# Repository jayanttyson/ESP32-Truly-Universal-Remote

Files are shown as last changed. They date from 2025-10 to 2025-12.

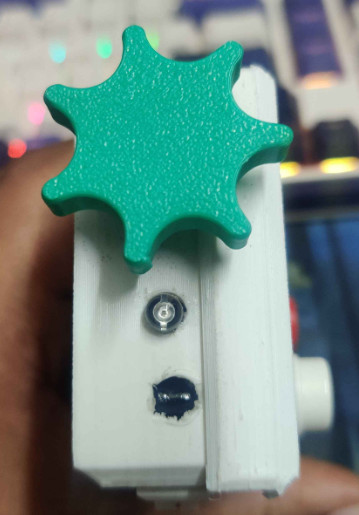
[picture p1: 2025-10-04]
Images/10.png

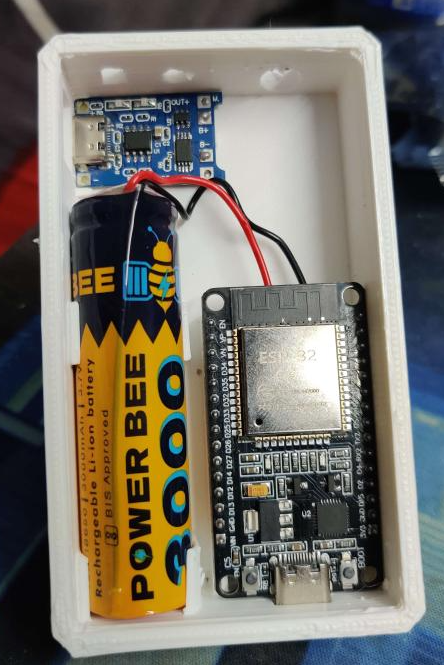
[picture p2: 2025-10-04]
Images/1.png

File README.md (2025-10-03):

# ESP32-Truly-Universal-Remote
ESP32-based universal remote control with IR, Bluetooth, and OLED display capabilities.
# Domninus Scepter: ESP32 IR/Bluetooth Remote Control


**Domninus Scepter** is a versatile ESP32-based IR/Bluetooth remote control system designed to control infrared devices such as TVs, air conditioners (ACs), and speakers, with additional Bluetooth keyboard functionality for media control. It features an OLED display for user interaction, a rotary encoder for navigation, and persistent storage for IR codes. The project supports a wide range of IR protocols and includes deep sleep for power efficiency.

## Features
- **IR Control**: Supports multiple IR protocols (NEC, Sony, Samsung, Coolix, Daikin, Mitsubishi, etc.) for TVs, ACs, and speakers.
- **Bluetooth Keyboard**: Controls media playback (play/pause, volume, mute) on Android/Windows devices via BLE.
- **OLED Display**: Shows menu, selected profile, battery status, and feedback messages.
- **Rotary Encoder**: Navigate profiles and modes with a rotary encoder and button.
- **Persistent Storage**: Saves IR codes and settings using the ESP32's NVS (Preferences).
- **Battery Monitoring**: Displays battery percentage based on voltage readings.
- **Deep Sleep**: Enters low-power mode after 15 seconds of inactivity to conserve battery.
- **Debug Mode**: Extensive serial output for debugging (enable with `#define DEBUG`).

## Hardware Requirements
- **ESP32 Board** (e.g., ESP32 DevKitC)
- **IR Receiver** (e.g., TSOP4838, connected to GPIO 15)
- **IR LED** (connected to GPIO 4)
- **OLED Display** (128x64, SSD1306, I2C, address 0x3C)
- **Rotary Encoder** (CLK: GPIO 25, DT: GPIO 26, SW: GPIO 27)
- **Push Buttons**:
  - BTN1 (Play/Pause): GPIO 33
  - BTN2 (Volume Up): GPIO 32
  - BTN3 (Mute): GPIO 13
  - BTN4 (Volume Down): GPIO 12
  - REC (Device Switch/Record): GPIO 5
- **Battery Monitoring**: Voltage divider connected to GPIO 34, used 2 x 1MΩ for Minimum Battery Drainage
- **Debug LED**: GPIO 2 {inbuild LED}/(optional, for visual feedback)
- 2N2222 General Purpose Transistor for IR LED
- 5v voltage regulator for powering the ESP32 with a stable Voltage
- 0.1uf Ceramic Capacitor at GPIO34 to GND for signal filtering (highly recomended)

## Software Requirements
- **Arduino IDE** (2.x recommended)
- **ESP32 Board Support**: Install via Boards Manager (`esp32` by Espressif)
- **Libraries**:
  - [IRremoteESP8266](https://github.com/crankyoldgit/IRremoteESP8266) (v2.8.2 or higher)
  - [Adafruit_SSD1306](https://github.com/adafruit/Adafruit_SSD1306) (for OLED)
  - [Preferences](https://github.com/espressif/arduino-esp32) (included with ESP32 core)
  - [NimBLE-Arduino](https://github.com/h2zero/NimBLE-Arduino) (for BLE)
  - [BleKeyboard](https://github.com/T-vK/ESP32-BLE-Keyboard) (for Bluetooth keyboard)

## Installation
1. **Clone the Repository**:
   ```bash
   git clone https://github.com/jayanttyson/ESP32-Truly-Universal-Remote.git
Install Arduino IDE:Download and install from arduino.cc.

Install ESP32 Board Support:In Arduino IDE, go to File > Preferences, add the following to Additional Boards Manager URLs:

https://raw.githubusercontent.com/espressif/arduino-esp32/master/package_esp32_index.json

Go to Tools > Board > Boards Manager, search for esp32, and install.

Install Libraries:In Arduino IDE, go to Sketch > Include Library > Manage Libraries.
Install IRremoteESP8266 (v2.8.2+), Adafruit_SSD1306, NimBLE-Arduino, and BleKeyboard.

Open the Sketch:Open domninus_scepter.ino from the cloned repository in Arduino IDE.

Configure and Upload:Select your ESP32 board under Tools > Board (e.g., ESP32 Dev Module).
Connect the ESP32 via USB, select the correct port under Tools > Port.
Upload the sketch (Sketch > Upload).

UsagePower On:Connect the ESP32 to a power source (e.g., battery or USB).
The OLED displays the menu with available profiles: TV, AC, SPK, AC_X, BT.

Navigate Profiles:Rotate the encoder to highlight a profile.
Press the encoder button to select the profile or toggle between menu and control mode.

Record IR Commands:In control mode, press the REC button (GPIO 5) to enter record mode (REC appears on OLED).
Point the target remote at the IR receiver and press a button.
If successful, the OLED shows "Signal captured! Press BTN1/2/3/4 to save".
Press a button (1-4) to save the IR code to that button for the current profile.

Send IR Commands:In control mode, press BTN1, BTN2, BTN3, or BTN4 to send the saved IR command.
For AC profiles (AC, AC_X), supports protocols like Coolix, Daikin, etc.
For TV/SPK, supports NEC, Sony, etc., or raw IR codes.

Bluetooth Mode:Select the BT profile.
Pair with a device (Android/Windows) via Bluetooth settings (device name: Domninus Scepter).
Use BTN1 (Play/Pause), BTN2 (Volume Up), BTN3 (Mute), BTN4 (Volume Down).
Press REC to switch between Android and Windows profiles.

Battery Monitoring:Battery percentage is displayed on the OLED, updated every 30 seconds.

Deep Sleep:The device enters deep sleep after 15 seconds of inactivity to save power.
Wake by pressing the encoder button (GPIO 27).

DebuggingEnable Debug Mode:Uncomment #define DEBUG in the sketch to enable serial output at 115200 baud.
Open the Serial Monitor (Tools > Serial Monitor) to view logs, including:IR capture details (protocol, value, raw timings).
Profile load/save status.
Bluetooth connection status.

Common Issues:IR Commands Not Working:Ensure IRremoteESP8266 is v2.8.2 or higher (older versions may cause compilation errors).
Check IR receiver/emitter wiring (GPIO 15 for receiver, GPIO 4 for emitter).
Verify the IR code was captured and saved (check Serial Monitor for Saved AC ... or Saved ...).

Compilation Errors:If enableIRIn() errors occur, update IRremoteESP8266 to v2.8.2+ or use the provided modified sketch for older versions.
Ensure all libraries are installed and up-to-date.

Bluetooth Issues:Reset BLE by pressing REC in BT profile to restart advertising.
Check Serial Monitor for Bluetooth initialized or BT Not Connected!.

Timer Errors (gptimer_register_to_group):Ensure irrecv.disableIRIn() is called before irsend operations (handled in the sketch).
If persistent, disable BLE temporarily to isolate conflicts.

Profile Persistence:If profiles don’t save, clear NVS with a sketch like:cpp

#include <Preferences.h>
void setup() {
  Preferences prefs;
  prefs.begin("IRRemote", false);
  prefs.clear();
  prefs.end();
  Serial.begin(115200);
  Serial.println("NVS cleared");
}
void loop() {}

Example Serial OutputOn IR Capture (AC Profile):

=== IR Capture Debug ===
Profile: AC
Decode type: COOLIX
Value: 0x123456
Raw length: 68
...
Saved AC COOLIX
AC value: 0x123456, len: 0
Saved AC raw: 68

On Profile Load:

Loaded profile AC
BTN1 AC value: 0x123456
BTN1 AC proto: COOLIX
BTN1 raw len: 68

On Command Send:

Sending AC cmd for BTN1: proto=COOLIX, value=0x123456, len=0, raw_len=68
SENT COOLIX
IR receiver re-enabled after sendACCmd

ContributingContributions are welcome! Please:Fork the repository.
Create a feature branch (git checkout -b feature/your-feature).
Commit changes (git commit -m 'Add your feature').
Push to the branch (git push origin feature/your-feature).
Open a Pull Request.

LicenseThis project is licensed under the MIT License. See the LICENSE file for details.AcknowledgmentsIRremoteESP8266 for IR protocol support.
Adafruit_SSD1306 for OLED display drivers.
NimBLE-Arduino and BleKeyboard for Bluetooth functionality.

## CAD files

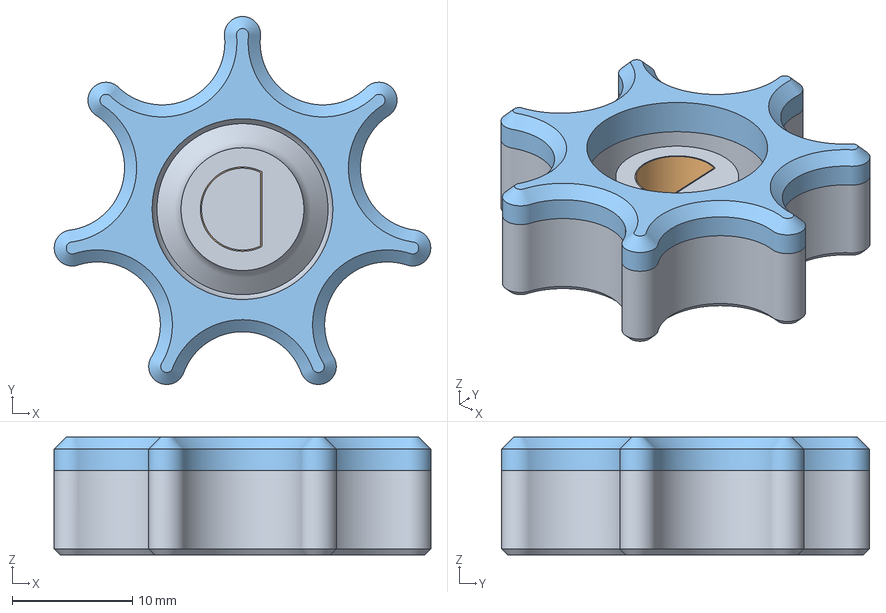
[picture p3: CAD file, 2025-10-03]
3D Models/Dshaft 6mm knob.3mf
31.3 x 30.6 x 9.80 mm

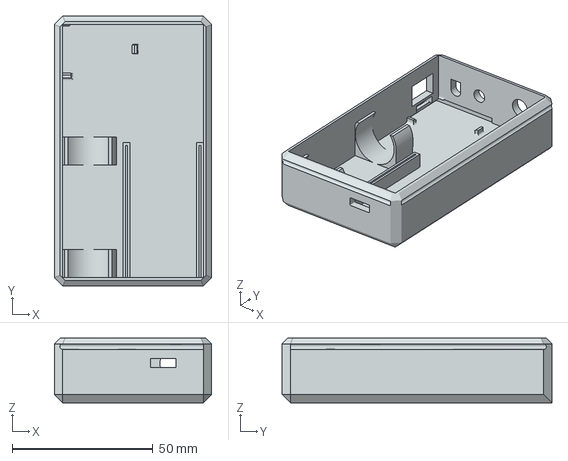
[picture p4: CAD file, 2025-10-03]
3D Models/Base.3mf
56.0 x 96.0 x 23.0 mm

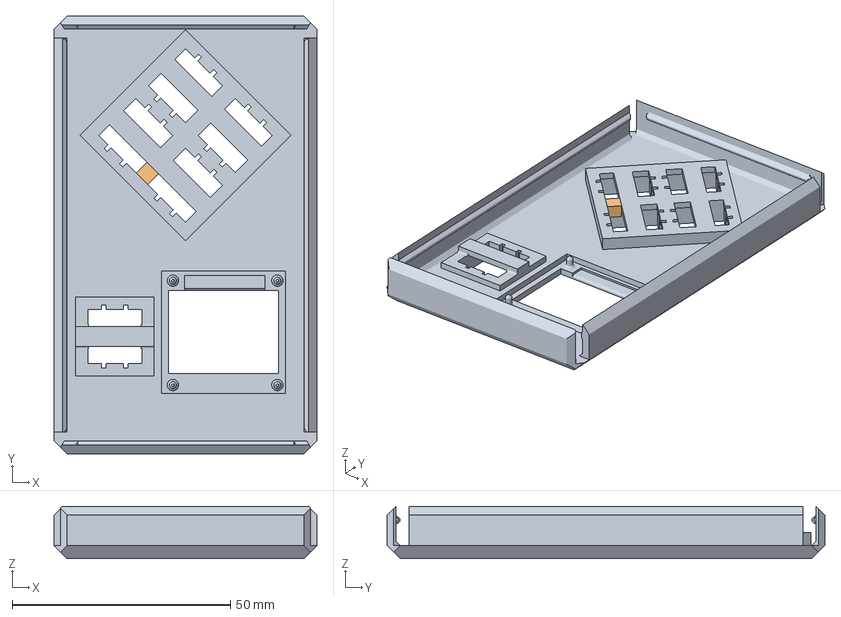
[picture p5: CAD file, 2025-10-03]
3D Models/Face.3mf
60.2 x 100.2 x 12.0 mm

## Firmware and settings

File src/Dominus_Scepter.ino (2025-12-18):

#include <Arduino.h>
#include <IRremoteESP8266.h>
#include <IRrecv.h>
#include <IRsend.h>
#include <ir_Voltas.h>
#include <ir_Coolix.h>
#include <ir_Daikin.h>
#include <ir_Mitsubishi.h>
#include <ir_Toshiba.h>
#include <ir_Fujitsu.h>
#include <ir_LG.h>
#include <ir_Haier.h>
#include <ir_Hitachi.h>
#include <ir_Panasonic.h>
#include <ir_Samsung.h>
#include <ir_Whirlpool.h>
#include <ir_Gree.h>
#include <ir_Midea.h>
#include <ir_Tcl.h>
#include <ir_Carrier.h>
#include <ir_Sharp.h>
#include <IRac.h>
#include <IRutils.h>
#include <Wire.h>
#include <Adafruit_SSD1306.h>
#include <Preferences.h>
#include <WiFi.h>
#include <NimBLEDevice.h>
#include <BleKeyboard.h>
#include <esp_task_wdt.h>

#define DECODE_HASH
#define DEBUG // Comment in for serial debugging
// Change Partition Sceheme to No OTA (2MB APP / 2MB SPIFFS)  for serial debugging 
// ==== Battery Monitoring ====
#define BATTERY_PIN 34
#define VOLTAGE_DIVIDER_RATIO 2.993
#define ADC_VREF 2573
#define ADC_MAX 4095
#define BATT_MIN_V 2.9
#define BATT_MAX_V 4.2
#define BATT_UPDATE_INTERVAL 30000
#define ADC_SAMPLES 64

// ==== OLED ====
#define SCREEN_WIDTH 128
#define SCREEN_HEIGHT 64
#define OLED_ADDRESS 0x3C

// ==== Rotary Encoder ====
#define CLK_PIN 25
#define DT_PIN 26
#define SW_PIN 27

// ==== Buttons ====
#define BTN1_PIN 33 // Play/Pause
#define BTN2_PIN 32 // Volume Up
#define BTN3_PIN 13 // Mute
#define BTN4_PIN 12 // Volume Down
#define REC_BTN_PIN 5 // Device switch in BT mode

// ==== IR ====
#define IR_SEND_PIN 4
#define IR_RECV_PIN 15
#define DEBUG_LED 2

// ===== AC-OPTIMIZED IR SETTINGS =====
const uint16_t kCaptureBufferSize = 2048;
const uint16_t kMaxRawLenNonAC = 1024;
const uint8_t kTimeout = 100;
const uint16_t kMinUnknownSize = 12;
const int MAX_RAW_LEN = 500;
const uint16_t MAX_AC_STATE_LEN = 32;
const int AC_RAW_FREQ = 38;
const int TV_RAW_FREQ = 38;
const int SPK_RAW_FREQ = 38;

// Deep sleep timeout
#define SLEEP_TIMEOUT 20000

// Bluetooth settings
#define BT_DEVICE_NAME "Dominus Scepter"
BleKeyboard bleKeyboard(BT_DEVICE_NAME, "ESP32", 100);
bool isBLEInitialized = false;
unsigned long lastAdvertisingStart = 0;
const unsigned long advertisingTimeout = 30000;
String deviceNames[] = {"None", "Android", "Windows"};
int connectedDeviceIndex = 0;

RTC_DATA_ATTR int savedCurrentIndex = 0;

// Volatile variables for ISR
volatile bool encoderChanged = false;
volatile int encoderDirection = 0;
volatile bool buttonPressed[5] = {false};
volatile bool encoderBtnPressed = false;
volatile unsigned long lastButtonTime = 0;
const unsigned long DEBOUNCE_TIME = 200;

bool isDisplayOn = true;
bool needsDisplayUpdate = false;
bool wdtInitialized = false;
int batteryPercentage = 100;
unsigned long lastBatteryUpdate = 0;

struct IRCode {
  uint16_t data[MAX_RAW_LEN];
  uint16_t length = 0;
};

struct ACCode {
  uint8_t data[MAX_AC_STATE_LEN];
  uint16_t length = 0;
  decode_type_t protocol = UNKNOWN;
  String description = "";
  uint64_t value = 0;
};

struct RemoteProfile {
  char name[10];
  uint64_t command1, command2, command3, command4;
  int8_t proto1, proto2, proto3, proto4;
  IRCode raw1, raw2, raw3, raw4;
  ACCode ac1, ac2, ac3, ac4;
};

RemoteProfile remotes[] = {
  {"TV", 0, 0, 0, 0, -1, -1, -1, -1, {}, {}, {}, {}, {}, {}, {}, {}},
  {"AC", 0, 0, 0, 0, -1, -1, -1, -1, {}, {}, {}, {}, {}, {}, {}, {}},
  {"SPK", 0, 0, 0, 0, -1, -1, -1, -1, {}, {}, {}, {}, {}, {}, {}, {}},
  {"AC_X", 0, 0, 0, 0, -1, -1, -1, -1, {}, {}, {}, {}, {}, {}, {}, {}},
  {"BT", 0, 0, 0, 0, -1, -1, -1, -1, {}, {}, {}, {}, {}, {}, {}, {}}
};

const int numRemotes = sizeof(remotes) / sizeof(remotes[0]);

int currentIndex = 0;
int highlighted = 0;
bool isMenu = true;
bool recordMode = false;
bool hasReceived = false;
decode_results lastReceived;
uint64_t lastCapturedCode = 0;
int8_t lastCapturedProto = -1;
ACCode lastCapturedAC = {{0}, 0, UNKNOWN, "", 0};
unsigned long lastBlink = 0;
bool recVisible = false;
unsigned long lastDisplayUpdate = 0;
unsigned long lastActivity = 0;
unsigned long feedbackStart = 0;
bool showingFeedback = false;

IRrecv irrecv(IR_RECV_PIN, kCaptureBufferSize, kTimeout, true);
IRsend irsend(IR_SEND_PIN);
IRac ac(IR_SEND_PIN);
Adafruit_SSD1306 display(SCREEN_WIDTH, SCREEN_HEIGHT, &Wire, -1);
Preferences prefs;

int voltageToPercentage(float voltage) {
  if (voltage >= 4.20) return 100;
  if (voltage <= 2.90) return 0;
  float voltagePoints[] = {4.20, 4.10, 4.00, 3.90, 3.80, 3.70, 3.60, 3.50, 3.20, 2.90};
  int percentagePoints[] = {100, 90, 80, 70, 50, 30, 20, 10, 5, 0};
  int numPoints = 10;
  for (int i = 0; i < numPoints - 1; i++) {
    if (voltage <= voltagePoints[i] && voltage > voltagePoints[i + 1]) {
      float voltageRange = voltagePoints[i] - voltagePoints[i + 1];
      int percentageRange = percentagePoints[i] - percentagePoints[i + 1];
      float fraction = (voltage - voltagePoints[i + 1]) / voltageRange;
      return percentagePoints[i + 1] + (int)(fraction * percentageRange + 0.5);
    }
  }
  return 0;
}

void updateBatteryPercentage() {
  long adcSum = 0;
  for (int i = 0; i < ADC_SAMPLES; i++) {
    adcSum += analogRead(BATTERY_PIN);
    ets_delay_us(100);
  }
  int adcValue = adcSum / ADC_SAMPLES;
  if (adcValue < 100 || adcValue > 4000) {
#ifdef DEBUG
    Serial.println("Error: Invalid ADC reading!");
    Serial.printf("Raw ADC: %d\n", adcValue);
#endif
    lastBatteryUpdate = millis();
    return;
  }
  float voltage = (adcValue * (ADC_VREF / 1000.0) / ADC_MAX) * VOLTAGE_DIVIDER_RATIO;
  batteryPercentage = voltageToPercentage(voltage);
#ifdef DEBUG
  Serial.printf("Battery ADC: %d, Voltage: %.2fV, Percentage: %d%%\n", adcValue, voltage, batteryPercentage);
#endif
  lastBatteryUpdate = millis();
}

void resetBLE(bool clearBonds = false) {
  if (isBLEInitialized) {
    NimBLEAdvertising* pAdvertising = NimBLEDevice::getAdvertising();
    if (pAdvertising) pAdvertising->stop();
    bleKeyboard.end();
    if (clearBonds) NimBLEDevice::deleteAllBonds();
    delay(200);
    isBLEInitialized = false;
  }
  NimBLEDevice::init(BT_DEVICE_NAME);
  NimBLEDevice::setPower(ESP_PWR_LVL_P9);
  NimBLEDevice::setMTU(185);
  bleKeyboard.begin();
  NimBLEAdvertising* pAdvertising = NimBLEDevice::getAdvertising();
  pAdvertising->setMinInterval(80);
  pAdvertising->setMaxInterval(128);
  pAdvertising->addServiceUUID(NimBLEUUID("1812"));
  pAdvertising->setName(BT_DEVICE_NAME);
  pAdvertising->setAppearance(0x03C0);
  pAdvertising->start();
  lastAdvertisingStart = millis();
  isBLEInitialized = true;
#ifdef DEBUG
  Serial.println("Bluetooth initialized");
#endif
  showFeedback("Pair with PC");
}

void IRAM_ATTR handleEncoder() {
  static int lastClk = HIGH;
  int clk = digitalRead(CLK_PIN);
  if (lastClk != clk) {
    int dt = digitalRead(DT_PIN);
    encoderDirection = (clk != dt) ? 1 : -1;
    encoderChanged = true;
  }
  lastClk = clk;
}

void IRAM_ATTR handleEncoderButton() {
  static unsigned long lastInterruptTime = 0;
  unsigned long currentTime = millis();
  if (currentTime - lastInterruptTime > DEBOUNCE_TIME) {
    encoderBtnPressed = true;
    lastButtonTime = currentTime;
    lastInterruptTime = currentTime;
  }
}

void IRAM_ATTR handleButton() {
  static unsigned long lastInterruptTime = 0;
  unsigned long currentTime = millis();
  if (currentTime - lastInterruptTime < DEBOUNCE_TIME) return;
  lastInterruptTime = currentTime;
  lastButtonTime = currentTime;
  if (digitalRead(BTN1_PIN) == LOW) buttonPressed[0] = true;
  else if (digitalRead(BTN2_PIN) == LOW) buttonPressed[1] = true;
  else if (digitalRead(BTN3_PIN) == LOW) buttonPressed[2] = true;
  else if (digitalRead(BTN4_PIN) == LOW) buttonPressed[3] = true;
  else if (digitalRead(REC_BTN_PIN) == LOW) buttonPressed[4] = true;
}

void checkWakeupButtons() {
  if (encoderBtnPressed) {
    noInterrupts();
    encoderBtnPressed = false;
    interrupts();
#ifdef DEBUG
    Serial.println("Woke up via SW_PIN press");
#endif
    isMenu = !isMenu;
    if (isMenu) {
      highlighted = currentIndex;
      showMenu();
    } else {
      currentIndex = highlighted;
      prefs.putInt("currentIndex", currentIndex);
      showSelected();
    }
    lastActivity = millis();
  }
}

void manageDisplayPower() {}

void setup() {
#ifdef DEBUG
  Serial.begin(115200);
  delay(100);
  Serial.println("Setup started");
#endif
  analogReadResolution(12);
  pinMode(BATTERY_PIN, INPUT);
  updateBatteryPercentage();
  pinMode(CLK_PIN, INPUT_PULLUP);
  pinMode(DT_PIN, INPUT_PULLUP);
  pinMode(SW_PIN, INPUT_PULLUP);
  pinMode(BTN1_PIN, INPUT_PULLUP);
  pinMode(BTN2_PIN, INPUT_PULLUP);
  pinMode(BTN3_PIN, INPUT_PULLUP);
  pinMode(BTN4_PIN, INPUT_PULLUP);
  pinMode(REC_BTN_PIN, INPUT_PULLUP);
  pinMode(DEBUG_LED, OUTPUT);
  digitalWrite(DEBUG_LED, LOW);
  attachInterrupt(digitalPinToInterrupt(CLK_PIN), handleEncoder, CHANGE);
  attachInterrupt(digitalPinToInterrupt(SW_PIN), handleEncoderButton, FALLING);
  attachInterrupt(digitalPinToInterrupt(BTN1_PIN), handleButton, FALLING);
  attachInterrupt(digitalPinToInterrupt(BTN2_PIN), handleButton, FALLING);
  attachInterrupt(digitalPinToInterrupt(BTN3_PIN), handleButton, FALLING);
  attachInterrupt(digitalPinToInterrupt(BTN4_PIN), handleButton, FALLING);
  attachInterrupt(digitalPinToInterrupt(REC_BTN_PIN), handleButton, FALLING);
  esp_sleep_enable_ext0_wakeup((gpio_num_t)SW_PIN, 0);
  esp_task_wdt_config_t wdt_config = {.timeout_ms = 15000, .idle_core_mask = 0, .trigger_panic = false};
  if (esp_task_wdt_init(&wdt_config) == ESP_OK) {
    wdtInitialized = true;
    esp_task_wdt_add(NULL);
  }
  WiFi.mode(WIFI_OFF);
  btStop();
  irsend.begin();
  irrecv.setUnknownThreshold(kMinUnknownSize);
  irrecv.disableIRIn(); // Initialize as disabled
  irrecv.enableIRIn();
#ifdef DEBUG
  Serial.println("IR receiver enabled in setup");
#endif
  if (!display.begin(SSD1306_SWITCHCAPVCC, OLED_ADDRESS)) {
#ifdef DEBUG
    Serial.println("SSD1306 allocation failed");
#endif
    for (;;);
  }
  Wire.setClock(100000);
  display.clearDisplay();
  display.setTextColor(SSD1306_WHITE);
  display.ssd1306_command(SSD1306_DISPLAYON);
  isDisplayOn = true;
  display.display();
  if (!prefs.begin("IRRemote", false)) {
#ifdef DEBUG
    Serial.println("Failed to initialize Preferences");
#endif
    showFeedback("Prefs Init Failed!");
    currentIndex = highlighted = 0;
  } else {
    loadProfiles();
    highlighted = currentIndex = prefs.getInt("currentIndex", currentIndex);
    if (currentIndex < 0 || currentIndex >= numRemotes) currentIndex = highlighted = 0;
  }
  resetBLE(false);
  showMenu();
  lastActivity = millis();
  isDisplayOn = true;
  needsDisplayUpdate = true;
}

#ifdef DEBUG
void debugProfile(int profile) {
  Serial.println("Profile: " + String(remotes[profile].name));
  for (int i = 1; i <= 4; i++) {
    uint64_t cmd = 0;
    int8_t proto = -1;
    uint16_t rawLen = 0;
    uint16_t acLen = 0;
    uint64_t acValue = 0;
    decode_type_t acProto = UNKNOWN;
    switch (i) {
      case 1: cmd = remotes[profile].command1; proto = remotes[profile].proto1; rawLen = remotes[profile].raw1.length; acLen = remotes[profile].ac1.length; acValue = remotes[profile].ac1.value; acProto = remotes[profile].ac1.protocol; break;
      case 2: cmd = remotes[profile].command2; proto = remotes[profile].proto2; rawLen = remotes[profile].raw2.length; acLen = remotes[profile].ac2.length; acValue = remotes[profile].ac2.value; acProto = remotes[profile].ac2.protocol; break;
      case 3: cmd = remotes[profile].command3; proto = remotes[profile].proto3; rawLen = remotes[profile].raw3.length; acLen = remotes[profile].ac3.length; acValue = remotes[profile].ac3.value; acProto = remotes[profile].ac3.protocol; break;
      case 4: cmd = remotes[profile].command4; proto = remotes[profile].proto4; rawLen = remotes[profile].raw4.length; acLen = remotes[profile].ac4.length; acValue = remotes[profile].ac4.value; acProto = remotes[profile].ac4.protocol; break;
    }
    Serial.printf("BTN%d cmd: 0x%llX\n", i, cmd);
    Serial.println("BTN" + String(i) + " proto: " + getProtocolName(proto));
    Serial.println("BTN" + String(i) + " raw len: " + String(rawLen));
    Serial.println("BTN" + String(i) + " AC len: " + String(acLen));
    Serial.println("BTN" + String(i) + " AC value: 0x" + String(acValue, HEX));
    Serial.println("BTN" + String(i) + " AC proto: " + String(typeToString(acProto)));
  }
}
#endif
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
void loop() {
  if (wdtInitialized) esp_task_wdt_reset();
  if (millis() - lastBatteryUpdate >= BATT_UPDATE_INTERVAL) {
    updateBatteryPercentage();
    needsDisplayUpdate = true;
  }
  if (millis() - lastActivity >= SLEEP_TIMEOUT) enterDeepSleep();
  manageDisplayPower();
  if (showingFeedback && millis() - feedbackStart >= 500) {
    showingFeedback = false;
    needsDisplayUpdate = true;
  }
  if (recordMode && millis() - lastBlink >= 500 && millis() - lastDisplayUpdate >= 500) {
    recVisible = !recVisible;
    lastBlink = millis();
    needsDisplayUpdate = true;
  }
  static bool lastRecordMode = false;
  static bool lastHasReceived = false;
  static int lastHighlighted = -1;
  static int lastCurrentIndex = -1;
  if ((lastRecordMode != recordMode || lastHasReceived != hasReceived ||
       lastHighlighted != highlighted || lastCurrentIndex != currentIndex ||
       needsDisplayUpdate) && millis() - lastDisplayUpdate >= 500) {
    if (isMenu) showMenu();
    else showSelected();
    lastRecordMode = recordMode;
    lastHasReceived = hasReceived;
    lastHighlighted = highlighted;
    lastCurrentIndex = currentIndex;
  }
  if (encoderChanged && isMenu) {
    noInterrupts();
    highlighted = (highlighted + encoderDirection + numRemotes) % numRemotes;
    encoderChanged = false;
    encoderDirection = 0;
    interrupts();
    lastActivity = millis();
    needsDisplayUpdate = true;
  }
  if (encoderBtnPressed) {
    noInterrupts();
    encoderBtnPressed = false;
    interrupts();
    isMenu = !isMenu;
    if (isMenu) {
      highlighted = currentIndex;
      showMenu();
    } else {
      currentIndex = highlighted;
      prefs.putInt("currentIndex", currentIndex);
      showSelected();
    }
    lastActivity = millis();
    needsDisplayUpdate = true;
  }
  processButtons();
  if (!bleKeyboard.isConnected() && isBLEInitialized && millis() - lastAdvertisingStart >= advertisingTimeout) {
    resetBLE(false);
  }
  static unsigned long captureStart = 0;
  static bool captureWaiting = false;
  if (recordMode && !captureWaiting && irrecv.decode(&lastReceived)) {
    unsigned long startTime = millis();
    digitalWrite(DEBUG_LED, HIGH);
    captureStart = millis();
    captureWaiting = true;
#ifdef DEBUG
    debugIRCapture(lastReceived);
#endif
    bool validSignal = false;
    bool isACProfile = (strcmp(remotes[currentIndex].name, "AC") == 0 || strcmp(remotes[currentIndex].name, "AC_X") == 0);
    uint16_t maxRawLen = isACProfile ? kCaptureBufferSize : kMaxRawLenNonAC;
    if (lastReceived.overflow) {
      showFeedback("Buffer Overflow!");
    } else if (lastReceived.rawlen > 0 || lastReceived.decode_type != UNKNOWN) {
      if (lastReceived.rawlen > maxRawLen) {
        showFeedback("Raw Too Long!");
      } else {
        validSignal = true;
      }
    }
    if (validSignal && isACProfile) {
      lastCapturedAC.protocol = lastReceived.decode_type;
      lastCapturedAC.description = String(typeToString(lastReceived.decode_type)) + " Cmd";
      if (isACProtocol(lastReceived.decode_type) && lastReceived.state && lastReceived.bits > 0) {
        size_t stateLen = (lastReceived.bits + 7) / 8;
        if (stateLen > MAX_AC_STATE_LEN) {
          showFeedback("State Too Large!");
        } else {
          memcpy(lastCapturedAC.data, lastReceived.state, stateLen);
          lastCapturedAC.length = stateLen;
          lastCapturedAC.value = lastReceived.value;
          hasReceived = true;
        }
      } else if (lastReceived.bits <= 64) {
        lastCapturedAC.value = lastReceived.value;
        size_t stateLen = (lastReceived.bits + 7) / 8;
        if (stateLen > MAX_AC_STATE_LEN) {
          showFeedback("State Too Large!");
        } else {
          for (int i = 0; i < stateLen; i++) {
            lastCapturedAC.data[i] = (lastReceived.value >> (i * 8)) & 0xFF;
          }
          lastCapturedAC.length = stateLen;
          hasReceived = true;
        }
      }
      if (lastReceived.rawlen > 0 && lastReceived.rawlen <= MAX_RAW_LEN && validateRawTimings(lastReceived)) {
        hasReceived = true;
      }
      if (hasReceived) {
        irrecv.disableIRIn();
        if (isACProtocol(lastCapturedAC.protocol) && (lastCapturedAC.length > 0 || lastCapturedAC.value != 0)) {
          digitalWrite(DEBUG_LED, HIGH);
          switch (lastCapturedAC.protocol) {
            case VOLTAS: {
              IRVoltas acVoltas(IR_SEND_PIN);
              acVoltas.begin();
              acVoltas.setRaw(lastCapturedAC.data);
              acVoltas.send();
#ifdef DEBUG
              Serial.println("SENT VOLTAS TEST");
#endif
              break;
            }
            case COOLIX: {
              IRCoolixAC acCoolix(IR_SEND_PIN);
              acCoolix.begin();
              acCoolix.setRaw((uint32_t)lastCapturedAC.value);
              acCoolix.send();
#ifdef DEBUG
              Serial.println("SENT COOLIX TEST");
#endif
              break;
            }
            case DAIKIN: {
              IRDaikinESP acDaikin(IR_SEND_PIN);
              acDaikin.begin();
              acDaikin.setRaw(lastCapturedAC.data);
              acDaikin.send();
#ifdef DEBUG
              Serial.println("SENT DAIKIN TEST");
#endif
              break;
            }
            case MITSUBISHI: {
              IRMitsubishiAC acMitsubishi(IR_SEND_PIN);
              acMitsubishi.begin();
              acMitsubishi.setRaw(lastCapturedAC.data);
              acMitsubishi.send();
#ifdef DEBUG
              Serial.println("SENT MITSUBISHI TEST");
#endif
              break;
            }
            case TOSHIBA_AC: {
              IRToshibaAC acToshiba(IR_SEND_PIN);
              acToshiba.begin();
              acToshiba.setRaw(lastCapturedAC.data);
              acToshiba.send();
#ifdef DEBUG
              Serial.println("SENT TOSHIBA_AC TEST");
#endif
              break;
            }
            case FUJITSU_AC: {
              IRFujitsuAC acFujitsu(IR_SEND_PIN);
              acFujitsu.begin();
              acFujitsu.setRaw(lastCapturedAC.data, lastCapturedAC.length);
              acFujitsu.send();
#ifdef DEBUG
              Serial.println("SENT FUJITSU_AC TEST");
#endif
              break;
            }
            case HAIER_AC: {
              IRHaierAC acHaier(IR_SEND_PIN);
              acHaier.begin();
              acHaier.setRaw(lastCapturedAC.data);
              acHaier.send();
#ifdef DEBUG
              Serial.println("SENT HAIER_AC TEST");
#endif
              break;
            }
            case HITACHI_AC: {
              IRHitachiAc acHitachi(IR_SEND_PIN);
              acHitachi.begin();
              acHitachi.setRaw(lastCapturedAC.data);
              acHitachi.send();
#ifdef DEBUG
              Serial.println("SENT HITACHI_AC TEST");
#endif
              break;
            }
            case GREE: {
              IRGreeAC acGree(IR_SEND_PIN);
              acGree.begin();
              acGree.setRaw(lastCapturedAC.data);
              acGree.send();
#ifdef DEBUG
              Serial.println("SENT GREE TEST");
#endif
              break;
            }
            case MIDEA: {
              IRMideaAC acMidea(IR_SEND_PIN);
              acMidea.begin();
              acMidea.setRaw(lastCapturedAC.value);
              acMidea.send();
#ifdef DEBUG
              Serial.println("SENT MIDEA TEST");
#endif
              break;
            }
            case TCL112AC: {
              IRTcl112Ac acTcl(IR_SEND_PIN);
              acTcl.begin();
              acTcl.setRaw(lastCapturedAC.data);
              acTcl.send();
#ifdef DEBUG
              Serial.println("SENT TCL112AC TEST");
#endif
              break;
            }
            case CARRIER_AC: {
              IRCarrierAc64 acCarrier(IR_SEND_PIN);
              acCarrier.begin();
              acCarrier.setRaw(lastCapturedAC.value);
              acCarrier.send();
#ifdef DEBUG
              Serial.println("SENT CARRIER_AC TEST");
#endif
              break;
            }
            case WHIRLPOOL_AC: {
              IRWhirlpoolAc acWhirlpool(IR_SEND_PIN);
              acWhirlpool.begin();
              acWhirlpool.setRaw(lastCapturedAC.data);
              acWhirlpool.send();
#ifdef DEBUG
              Serial.println("SENT WHIRLPOOL_AC TEST");
#endif
              break;
            }
          }
          digitalWrite(DEBUG_LED, LOW);
        } else if (lastReceived.rawlen > 0) {
          digitalWrite(DEBUG_LED, HIGH);
          irsend.sendRaw((uint16_t*)lastReceived.rawbuf, lastReceived.rawlen, AC_RAW_FREQ);
          digitalWrite(DEBUG_LED, LOW);
#ifdef DEBUG
          Serial.println("SENT RAW TEST");
#endif
        }
        irrecv.enableIRIn();
#ifdef DEBUG
        Serial.println("IR receiver re-enabled after AC test");
#endif
      }
    } else if (validSignal) {
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

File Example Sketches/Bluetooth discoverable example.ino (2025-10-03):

#include <Arduino.h>
#include <NimBLEDevice.h>
#include <BleKeyboard.h>

#define DEBUG
#define BT_DEVICE_NAME "ESP32_MediaKey"
#define BUTTON_PIN 5 // Command and switch button
#define SHORT_PRESS_TIME 1000 // 1s for short press
#define DEBOUNCE_DELAY 50 // 50ms debounce

BleKeyboard bleKeyboard(BT_DEVICE_NAME, "ESP32NimBLE", 100);
bool isBLEInitialized = false;
unsigned long lastAdvertisingStart = 0;
unsigned long connectStartTime = 0;
const unsigned long advertisingTimeout = 10000; // 10s timeout
bool lastButtonState = HIGH; // Pull-up, HIGH = not pressed
unsigned long buttonPressStartTime = 0;
bool buttonHandled = false;
int connectedDeviceIndex = 0; // 0 = none, 1 = Android, 2 = Windows
String deviceNames[] = {"None", "Android", "Windows"};

void resetBLE(bool clearBonds = false) {
  if (isBLEInitialized) {
    NimBLEAdvertising* pAdvertising = NimBLEDevice::getAdvertising();
    if (pAdvertising) {
      pAdvertising->stop();
#ifdef DEBUG
      Serial.println("Advertising stopped");
#endif
    }
    bleKeyboard.end();
    if (clearBonds) {
      NimBLEDevice::deleteAllBonds();
#ifdef DEBUG
      Serial.println("Bonding data cleared");
#endif
    }
    delay(200); // Stabilize stack
    isBLEInitialized = false;
#ifdef DEBUG
    Serial.println("BLE reset complete");
#endif
  }
  NimBLEDevice::init(BT_DEVICE_NAME);
  NimBLEDevice::setSecurityAuth(true, true, true);
  NimBLEDevice::setPower(ESP_PWR_LVL_P9);
  bleKeyboard.begin();
  NimBLEAdvertising* pAdvertising = NimBLEDevice::getAdvertising();
  pAdvertising->setMinInterval(32); // 20ms
  pAdvertising->setMaxInterval(64); // 40ms
  pAdvertising->addServiceUUID(NimBLEUUID("1812"));
  pAdvertising->setName(BT_DEVICE_NAME);
  pAdvertising->setAppearance(0x03C0);
  pAdvertising->start();
  lastAdvertisingStart = millis();
  isBLEInitialized = true;
#ifdef DEBUG
  Serial.println("Bluetooth initialized with HID service");
#endif
}

void switchDevice() {
  NimBLEAdvertising* pAdvertising = NimBLEDevice::getAdvertising();
  if (pAdvertising) {
    pAdvertising->stop();
#ifdef DEBUG
    Serial.println("Advertising stopped for switch");
#endif
  }
  bleKeyboard.end();
#ifdef DEBUG
  Serial.println("Disconnected to switch device");
#endif
  delay(200); // Stabilize stack
  connectedDeviceIndex = (connectedDeviceIndex % 2) + 1;
#ifdef DEBUG
  Serial.printf("Switching to device: %s\n", deviceNames[connectedDeviceIndex].c_str());
#endif
  // Reset button state to ensure functionality post-switch
  lastButtonState = HIGH;
  buttonPressStartTime = 0;
  buttonHandled = false;
  // Restart advertising
  pAdvertising = NimBLEDevice::getAdvertising();
  pAdvertising->setMinInterval(32);
  pAdvertising->setMaxInterval(64);
  pAdvertising->addServiceUUID(NimBLEUUID("1812"));
  pAdvertising->setName(BT_DEVICE_NAME);
  pAdvertising->setAppearance(0x03C0);
  pAdvertising->start();
  lastAdvertisingStart = millis();
#ifdef DEBUG
  Serial.println("Advertising restarted for new device");
#endif
}

void setup() {
#ifdef DEBUG
  Serial.begin(115200);
  delay(100);
  Serial.println("Setup started");
#endif
  pinMode(BUTTON_PIN, INPUT_PULLUP);
  resetBLE(false);
}

void loop() {
  // Manual BLE reset ('r' for reset, 'b' for reset with bond clear)
  if (Serial.available()) {
    char c = Serial.read();
    if (c == 'r') {
      resetBLE(false);
    } else if (c == 'b') {
      resetBLE(true);
    }
  }

  // Button handling (short press: media, long press: switch)
  bool currentButtonState = digitalRead(BUTTON_PIN);
  if (currentButtonState != lastButtonState) {
    if (currentButtonState == LOW) { // Button pressed
      buttonPressStartTime = millis();
      buttonHandled = false;
#ifdef DEBUG
      Serial.println("Button pressed");
#endif
    } else if (currentButtonState == HIGH && !buttonHandled) { // Button released
      unsigned long pressDuration = millis() - buttonPressStartTime;
      if (pressDuration < SHORT_PRESS_TIME && bleKeyboard.isConnected()) { // Short press
        bleKeyboard.releaseAll();
        bleKeyboard.write(KEY_MEDIA_PLAY_PAUSE);
#ifdef DEBUG
        Serial.printf("Short press: Sent Play/Pause to %s\n", deviceNames[connectedDeviceIndex].c_str());
#endif
        delay(100);
        bleKeyboard.releaseAll();
      }
      buttonHandled = true;
    }
  }
  // Check for long press while button is held
  if (currentButtonState == LOW && !buttonHandled && millis() - buttonPressStartTime >= SHORT_PRESS_TIME) {
    switchDevice();
    buttonHandled = true;
  }
  lastButtonState = currentButtonState;

  if (bleKeyboard.isConnected()) {
    if (connectStartTime > 0) {
#ifdef DEBUG
      Serial.printf("Connected to %s in %lu ms\n", deviceNames[connectedDeviceIndex].c_str(), millis() - connectStartTime);
#endif
      connectStartTime = 0;
      bleKeyboard.releaseAll();
      delay(200);
#ifdef DEBUG
      Serial.println("Released all keys to refresh HID service");
#endif
    }
  } else {
#ifdef DEBUG
    Serial.println("Not connected, advertising...");
#endif
    if (connectStartTime == 0) {
      connectStartTime = millis();
    }
    if (millis() - lastAdvertisingStart >= advertisingTimeout) {
      NimBLEAdvertising* pAdvertising = NimBLEDevice::getAdvertising();
      pAdvertising->stop();
      delay(50);
      pAdvertising->setMinInterval(32);
      pAdvertising->setMaxInterval(64);
      pAdvertising->addServiceUUID(NimBLEUUID("1812"));
      pAdvertising->setName(BT_DEVICE_NAME);
      pAdvertising->setAppearance(0x03C0);
      pAdvertising->start();
      lastAdvertisingStart = millis();
#ifdef DEBUG
      Serial.println("Advertising restarted");
#endif
    }
  }
  delay(20);
}

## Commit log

2025-10-03 Add files via upload
    Rotary Encoder code was later changed from polling type to interpret type
2025-10-04 Create Circuit Diagram
2025-10-04 Create Pin Connections
2025-10-04 Update Circuit Diagram
2026-03-12 Update print statement from 'Hello' to 'Goodbye'
